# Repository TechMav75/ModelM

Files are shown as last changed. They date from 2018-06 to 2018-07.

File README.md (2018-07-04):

# Model M to USB converter

This is a drop in replacement for the controller board on an IBM Model M keyboard, part number 1391401.

You will find Gerber files, controller files, and the BOM to build your own board.

The board is designed to accomodate 16/12 pin and 16/8/4 pin setups. You will need to check your keyboard controller to see which connectors you will need.

If you need the 16/8/4 pin style, install the 8pin Trio Mate in the left hand holes of the 12pin connector. The 4pin will go in the obvious place on the right of the board.

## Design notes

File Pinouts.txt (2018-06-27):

1391401 keyboard Matrix

       J3.1     J3.2     J3.3     J3.4     J3.5     J3.6     J3.7     J3.8
J4.1    NC       NC      L-Ctrl    NC       NC       NC      R-Ctrl    NC
J4.2    NC     L-Shift    NC       NC       NC       NC     R-Shift    NC
J4.3   Esc      Tab       `~       1        Q        A        Z        NC
J4.4    NC      Caps      F1       2        W        S        X        NC
J4.5    F4       F3       F2       3        E        D        C        NC
J4.6    G        T        5        4        R        F        V        B
J4.7    F5    Backspace   F9      F10       NC       \|     Enter    Space
J4.8    H        Y        6        7        U        J        M        N
J4.9    F6       }]       +=       8        I        K        ,<       NC
J4.10   NC       F7       F8       9        O        L        .>       NC
J4.11   '"       {[       -_       0        P        ;        NC       /?
J4.12   NC       N4      Del      F11       N7       N1    Numlock    Down
J4.13   N0       N5      Ins      F12       N8       N2       N/     Right
J4.14   N.       N6      PGUP     PGDN      N9       N3       N*       N-
J4.15   UP       NC      Home     End       N+    N Enter    Pause    Left
J4.16  L-Alt     NC       NC    PrtScrn   ScrlLck    NC       NC     R-Alt

J8.1	Num Lock	(Will need a resistor between pin and Teensy)
J8.2	+5v
J8.3	Caps Lock	(Will need a resistor between pin and Teensy)
J8.4	Scroll Lock	(Will need a resistor between pin and Teensy)

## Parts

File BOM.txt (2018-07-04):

Part			Part Number		QTY	DigiKey Part #
16pin Trio Mate Conn	6-520315-6		1	6-520315-6-ND

8pin Trio Mate Conn	5-520315-8		1	5-520315-8-ND
4pin Trio Mate Conn	5-520315-4		1	A123169-ND

12pin Trio Mate Conn	6-520315-2		1	A123179-ND

Spade PCB Conn		4966			1	36-4966-ND
270ohm 0805 Resistor	CRG0805F270R		3	A126355CT-ND
Momentary Switch				1

Teensy++ 2.0

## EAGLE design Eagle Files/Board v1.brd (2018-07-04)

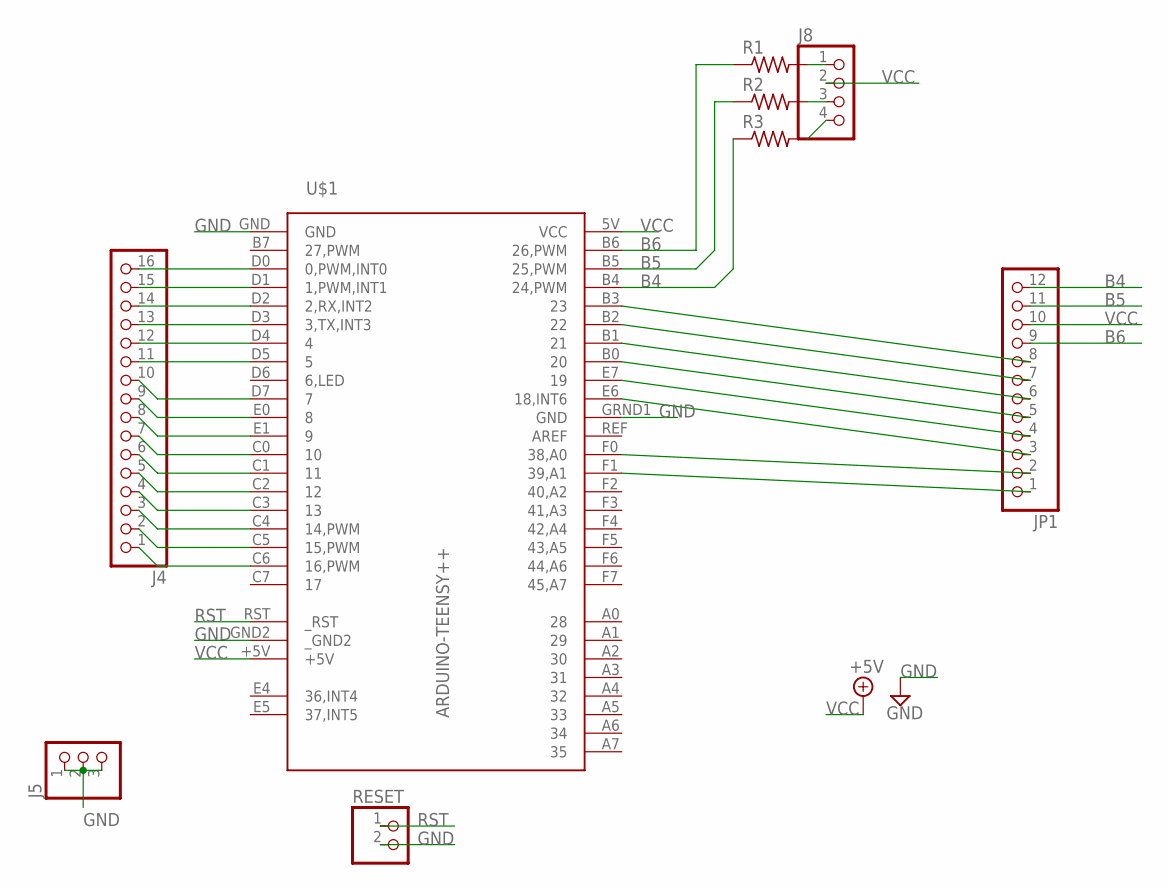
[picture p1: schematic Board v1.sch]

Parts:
J4: PINHD-1X16; 1X16
J5: PINHD-1X3; 1X03
J8: PINHD-1X4; 1X04
JP1: PINHD-1X12; 1X12
R1, R2, R3: R-US_R0805; R0805
RESET: PINHD-1X2; 1X02
U$1: ARDUINO-TEENSY++; TEENSY++

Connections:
B4: JP1.12, R3.1, U$1.B4 (24,PWM)
B5: JP1.11, R2.1, U$1.B5 (25,PWM)
B6: JP1.9, R1.1, U$1.B6 (26,PWM)
GND: J5.1, J5.2, J5.3, RESET.2, U$1.GND, U$1.GND2 (_GND2), U$1.GRND1 (GND)
unnamed: J4.16, U$1.D0 (0,PWM,INT0)
unnamed: J8.1, R1.2
unnamed: J8.3, R2.2
unnamed: J8.4, R3.2
unnamed: J4.15, U$1.D1 (1,PWM,INT1)
unnamed: J4.14, U$1.D2 (2,RX,INT2)
unnamed: J4.13, U$1.D3 (3,TX,INT3)
unnamed: J4.12, U$1.D4 (4)
unnamed: J4.11, U$1.D5 (5)
unnamed: J4.10, U$1.D7 (7)
unnamed: J4.9, U$1.E0 (8)
unnamed: J4.8, U$1.E1 (9)
unnamed: J4.7, U$1.C0 (10)
unnamed: J4.6, U$1.C1 (11)
unnamed: J4.5, U$1.C2 (12)
unnamed: J4.4, U$1.C3 (13)
unnamed: J4.3, U$1.C4 (14,PWM)
unnamed: J4.2, U$1.C5 (15,PWM)
unnamed: J4.1, U$1.C6 (16,PWM)
unnamed: JP1.8, U$1.B3 (23)
unnamed: JP1.7, U$1.B2 (22)
unnamed: JP1.6, U$1.B1 (21)
unnamed: JP1.5, U$1.B0 (20)
unnamed: JP1.4, U$1.E7 (19)
unnamed: JP1.3, U$1.E6 (18,INT6)
unnamed: JP1.2, U$1.F0 (38,A0)
unnamed: JP1.1, U$1.F1 (39,A1)
RST: RESET.1, U$1.RST (_RST)
VCC: J8.2, JP1.10, U$1.5V (VCC), U$1.+5V

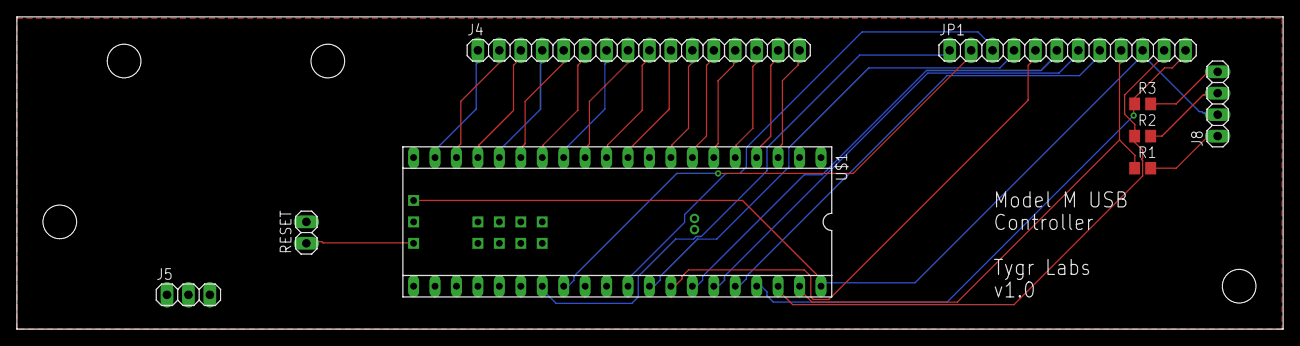
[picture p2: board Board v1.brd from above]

Board: 2 copper layers, 150.0 x 37.0 mm, 9 parts (0 on the bottom side), 33 nets.

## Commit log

2018-06-29 Updated board to include flood fill on ground planes.
2018-07-04 Modified schematic and board for 16/12 and 16/8/4 pin connector setups.
    [Board v1.brd, Board v1.sch]
